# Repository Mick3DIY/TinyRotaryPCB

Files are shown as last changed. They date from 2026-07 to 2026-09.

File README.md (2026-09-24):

<picture>
    MadeForBournsPec11r(forthebadge.com)
</picture>

# TinyRotaryPCB

A tiny PCB (with surface resistors) for the BOURNS PEC11R rotary encoder.

## Printed Circuit Board (PCB) :

As part of an educational project, the schematic and PCB are made with [KiCad](https://www.kicad.org) version 9 ([kicad](kicad/) folder).

:bulb: All important parameters are stored in the schematic/PCB editors **text variables** (common project variables).

The TinyRotaryPCB itself with the rotary encoder (in reverse side for panel mount), dimensions (mm) :

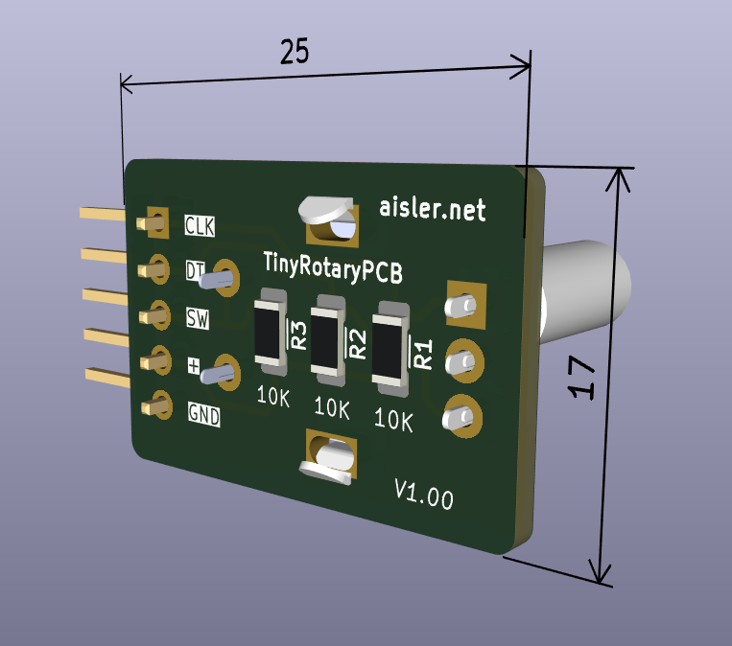
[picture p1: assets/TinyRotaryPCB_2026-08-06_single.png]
Single TinyRotaryPCB


The panelization option (2x2 boards with stencil) was generated with the KiCad plugin [KiKit](https://github.com/yaqwsx/KiKit), dimensions (mm) in [kicad/panel](kicad/panel/) folder :

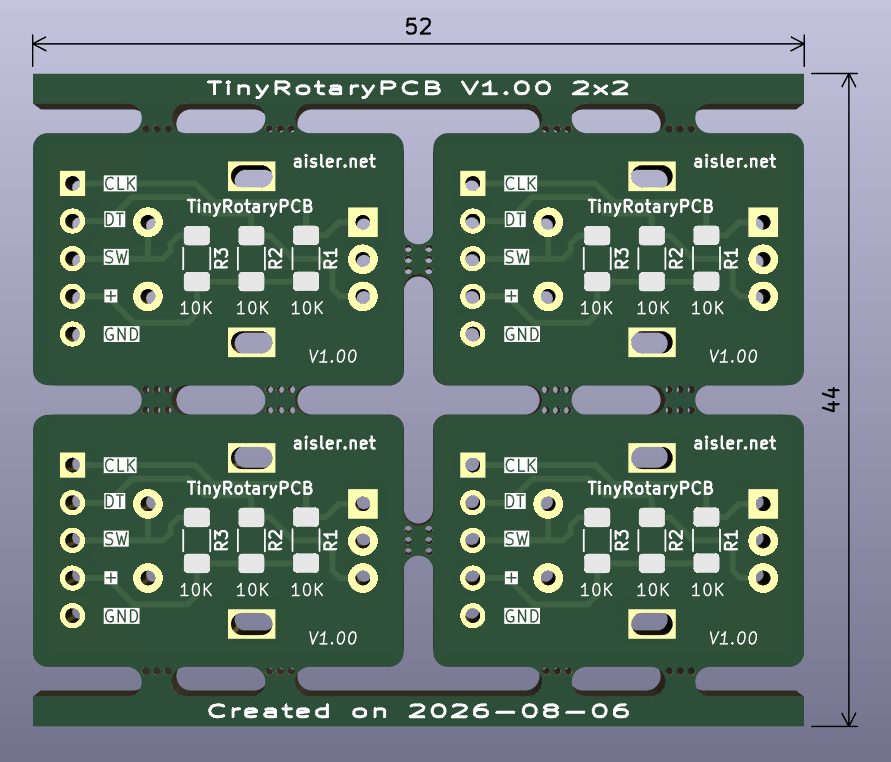
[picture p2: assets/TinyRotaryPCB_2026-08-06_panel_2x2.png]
Panelization TinyRotaryPCB


Thanks to [AISLER](https://aisler.net) PCB manufacturer :eu:

Other useful plugins for KiCad :
* AISLER Push for KiCad : https://github.com/aislerhq (with AISLER repository to always get the latest updates)
* Interactive HTML BOM : https://github.com/openscopeproject/InteractiveHtmlBom
* Board2Pdf : https://gitlab.com/dennevi/Board2Pdf
* Solarized Dark Theme : https://github.com/pointhi/kicad-color-schemes

Get a unique 10€ coupon code in <ins>your first order</ins> in [AISLER](https://aisler.net) with my referral code : `MakeInEurope-ECYPW` :heart:

The shell script to easily generate panels (in [kicad](kicad/) folder)… :laughing:

```shell
#!/bin/bash
# TinyRotaryPCB with KiCad and KiKit plugin for PCB panelization
# GitHub project : https://github.com/Mick3DIY/TinyRotaryPCB
# KiCad documentation : https://www.kicad.org
# KiKit plugin documentation : https://github.com/yaqwsx/KiKit

# Input and output files
INPUT_FILE="TinyRotaryPCB.kicad_pcb"
OUTPUT_DIR="panel"
OUTPUT_FILE="${OUTPUT_DIR}/TinyRotaryPCB_panel.kicad_pcb"

# Layout parameters, by default 2x2 -> panelize.sh <rows> <cols> parameters
LAYOUT_ROWS="${1:-2}"
LAYOUT_COLS="${2:-2}"
LAYOUT_SPACE="2mm"

# Tab parameters
TAB_TYPE="fixed"
TAB_HWIDTH="2mm"
TAB_VWIDTH="2mm"
TAB_VCOUNT="2"

# Cuts parameters
CUTS="mousebites; drill: 0.5mm; spacing: 0.75mm; offset: -0.3mm; prolong: 0.5mm"

# Framing parameters
FRAME_TYPE="railstb"
FRAME_WIDTH="2mm"
FRAME_SPACE="2mm"

# Text parameters
TEXT_HEIGHT="0.8mm"
TEXT_VOFFSET_POS="1mm"
TEXT_VOFFSET_NEG="-1mm"
TEXT_JUSTIFY="hjustify: center; vjustify: center;"
POST_MILLRADIUS="1mm"

# Ensure output directory exist
mkdir -p "${OUTPUT_DIR}"

# Kikit command with all parameters
kikit panelize \
    --layout "grid; rows: ${LAYOUT_ROWS}; cols: ${LAYOUT_COLS}; space: ${LAYOUT_SPACE}" \
    --tabs "${TAB_TYPE}; hwidth: ${TAB_HWIDTH}; vwidth: ${TAB_VWIDTH}; vcount: ${TAB_VCOUNT}" \
    --cuts "${CUTS}" \
    --framing "${FRAME_TYPE}; width: ${FRAME_WIDTH}; space: ${FRAME_SPACE};" \
    --text "simple; text: {boardTitle} {boardRevision} ${LAYOUT_COLS}x${LAYOUT_ROWS}; anchor: mt; voffset: ${TEXT_VOFFSET_POS}; height: ${TEXT_HEIGHT}; ${TEXT_JUSTIFY}" \
    --text2 "simple; text: Created on {boardDate}; anchor: mb; voffset: ${TEXT_VOFFSET_NEG}; height: ${TEXT_HEIGHT}; ${TEXT_JUSTIFY}" \
    --post "millradius: ${POST_MILLRADIUS}" \
    "${INPUT_FILE}" "${OUTPUT_FILE}"

# Check if the command succeeded
if [ $? -eq 0 ]; then
    echo "Panelization successful : ${OUTPUT_FILE}"
else
    echo "Error : Panelization failed"
    exit 1
fi
```

More panelization examples in KiKit plugin documentation : https://yaqwsx.github.io/KiKit/latest/panelization/examples/

## Logic analyser with the rotary encoder :

To understand how a rotary encoder "pulses" works, it is useful to visualise it with a software/hardware logic analysers.

Here an example with the same schematic (pins A, B, SW) in [Sigrok](https://sigrok.org) and PulseView softwares :

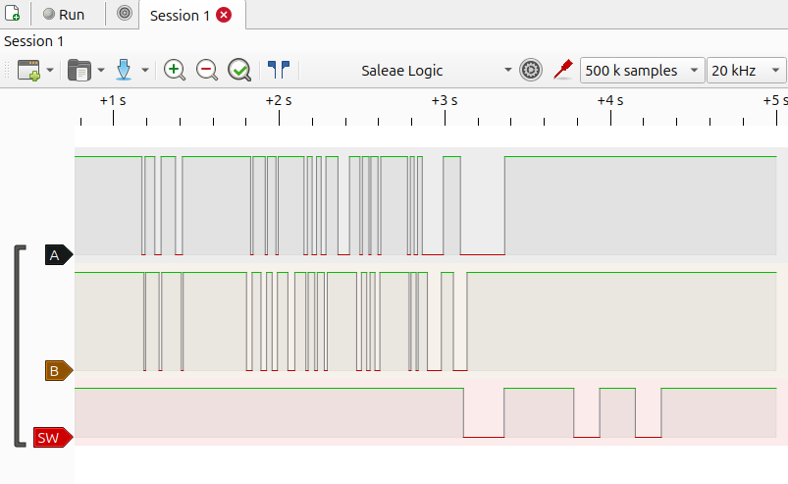
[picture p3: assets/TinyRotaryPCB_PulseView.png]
PulseViewExample


## TODO :

- [x] Add PDF files for the schematic, PCBs (single, panelization)
- [x] Add a screenshot from the logic analyser [Sigrok](https://sigrok.org)
- [x] Add link to the Elektor Ebook "Logic Analyzers in Practice" from Jörg Rippel
- [ ] Add more files and examples, any ideas ? :laughing:

## Documentation :

BOURNS PEC11R Series 12 mm incremental rotary encoder (PEC11R-4220F-S0024) :
* https://www.bourns.com/resources/rohs/encoders/contacting-encoders
* https://www.bourns.com/docs/product-datasheets/pec11r.pdf

Sigrok, PulseView softwares, all cross-platform : https://sigrok.org :clap:

Elektor Ebook "Logic Analyzers in Practice" from Jörg Rippel :
* https://www.elektor.fr/products/logic-analyzers-in-practice-e-book :ok_hand:

> [!NOTE]
> Big thanks to the open-source, [KiCad](https://www.kicad.org) and plugins communities. :heart:

Happy soldering & have fun ! :partying_face:

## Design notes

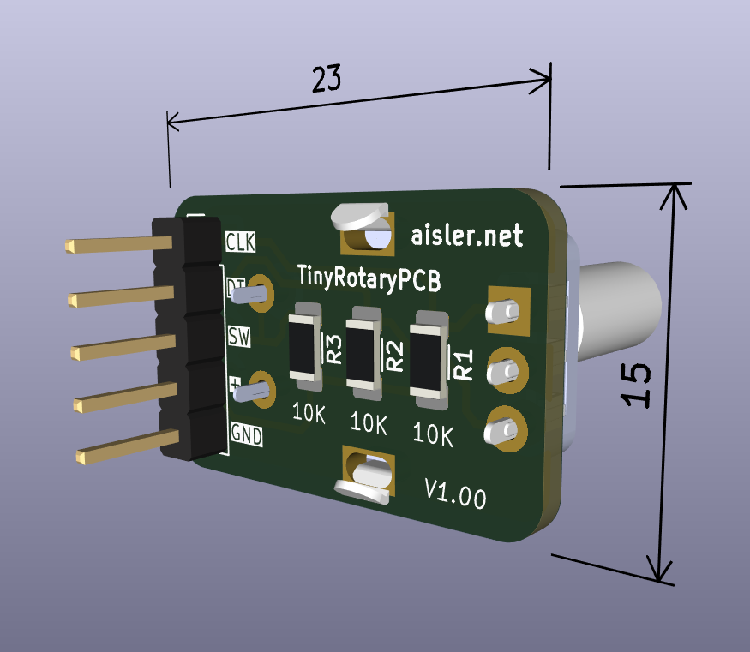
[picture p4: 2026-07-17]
assets/TinyRotaryPCB_2026-07-17_single.png

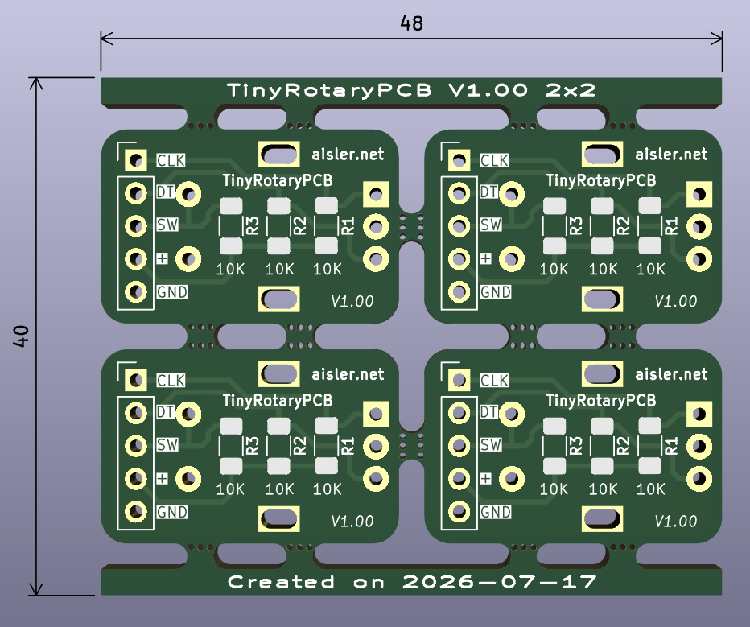
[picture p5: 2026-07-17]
assets/TinyRotaryPCB_2026-07-17_panel_2x2.png

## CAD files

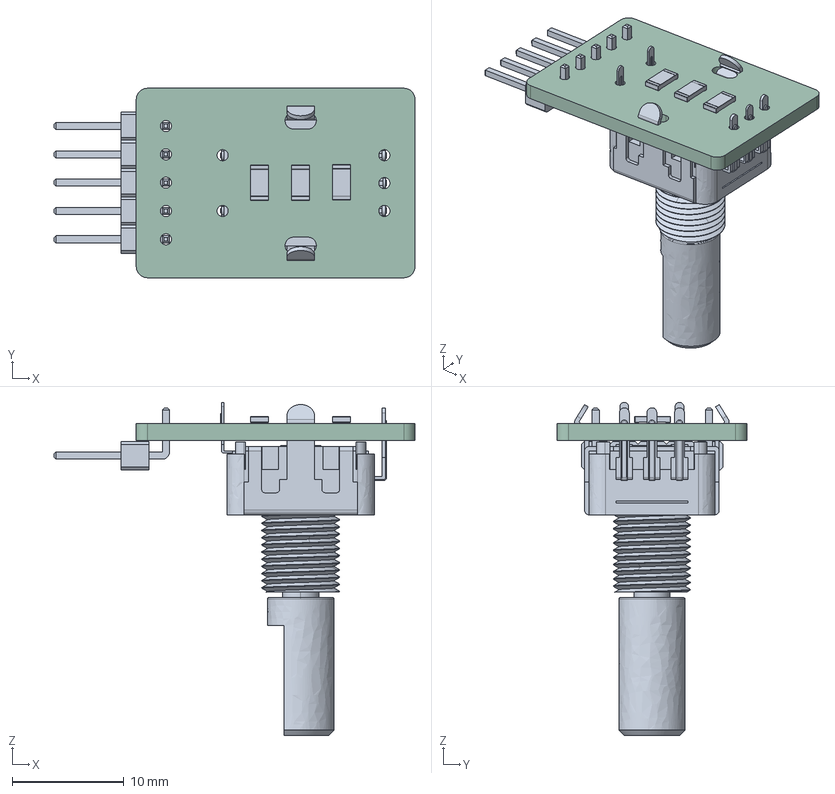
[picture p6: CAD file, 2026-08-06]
kicad/TinyRotaryPCB.step
32.4 x 17.0 x 29.9 mm
R_1206_3216Metric x 3
PinHeader_1x05_P2.54mm_Horizontal
PEC11R-4220F-S0024
TinyRotaryPCB_PCB

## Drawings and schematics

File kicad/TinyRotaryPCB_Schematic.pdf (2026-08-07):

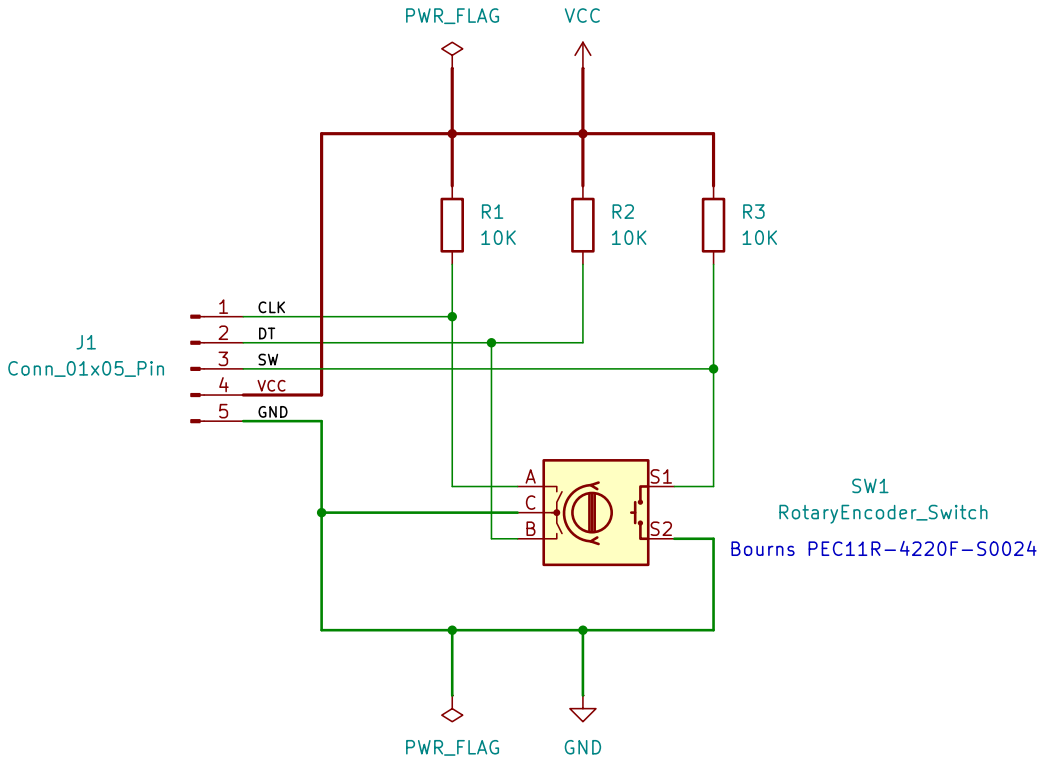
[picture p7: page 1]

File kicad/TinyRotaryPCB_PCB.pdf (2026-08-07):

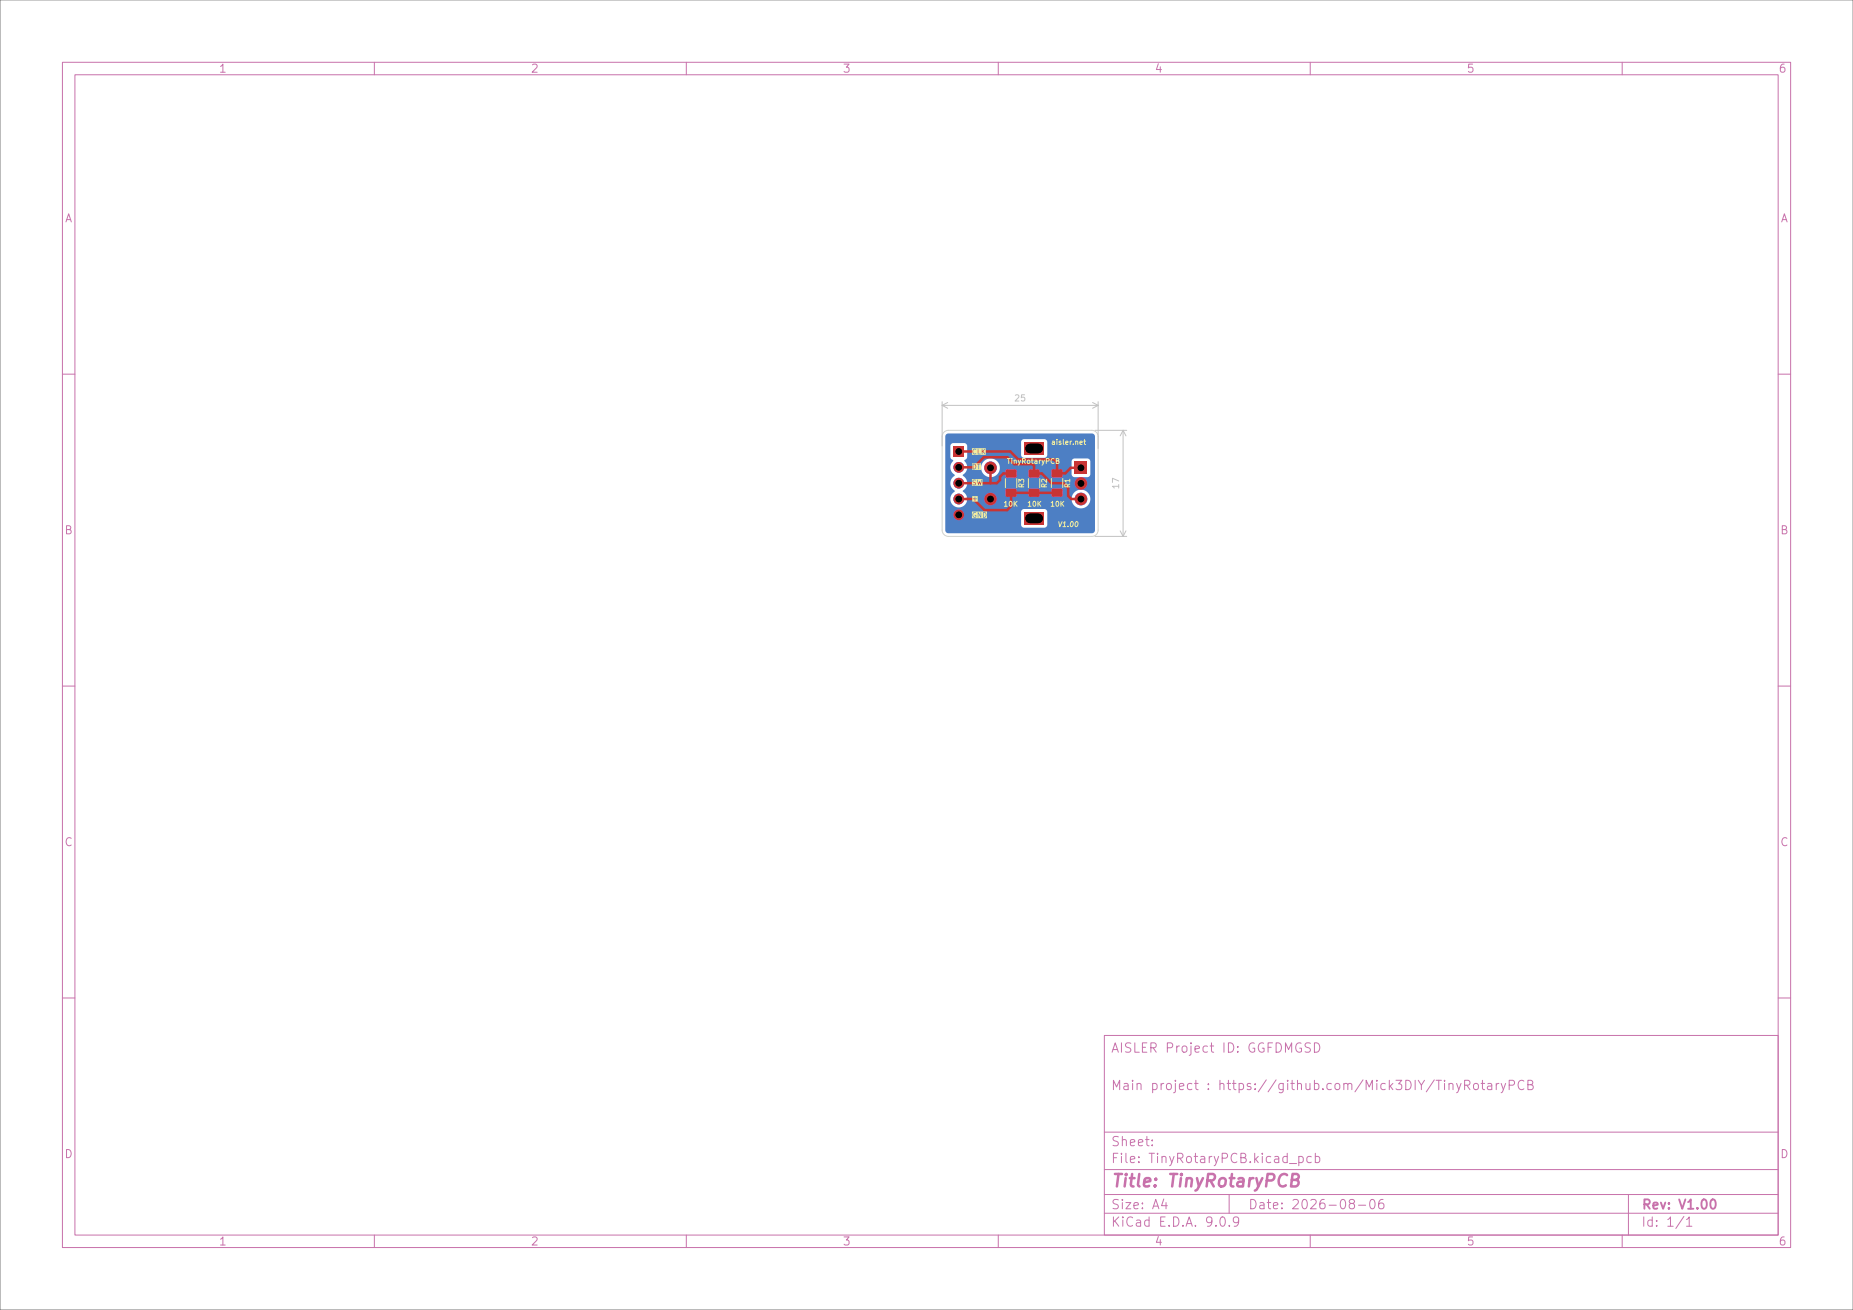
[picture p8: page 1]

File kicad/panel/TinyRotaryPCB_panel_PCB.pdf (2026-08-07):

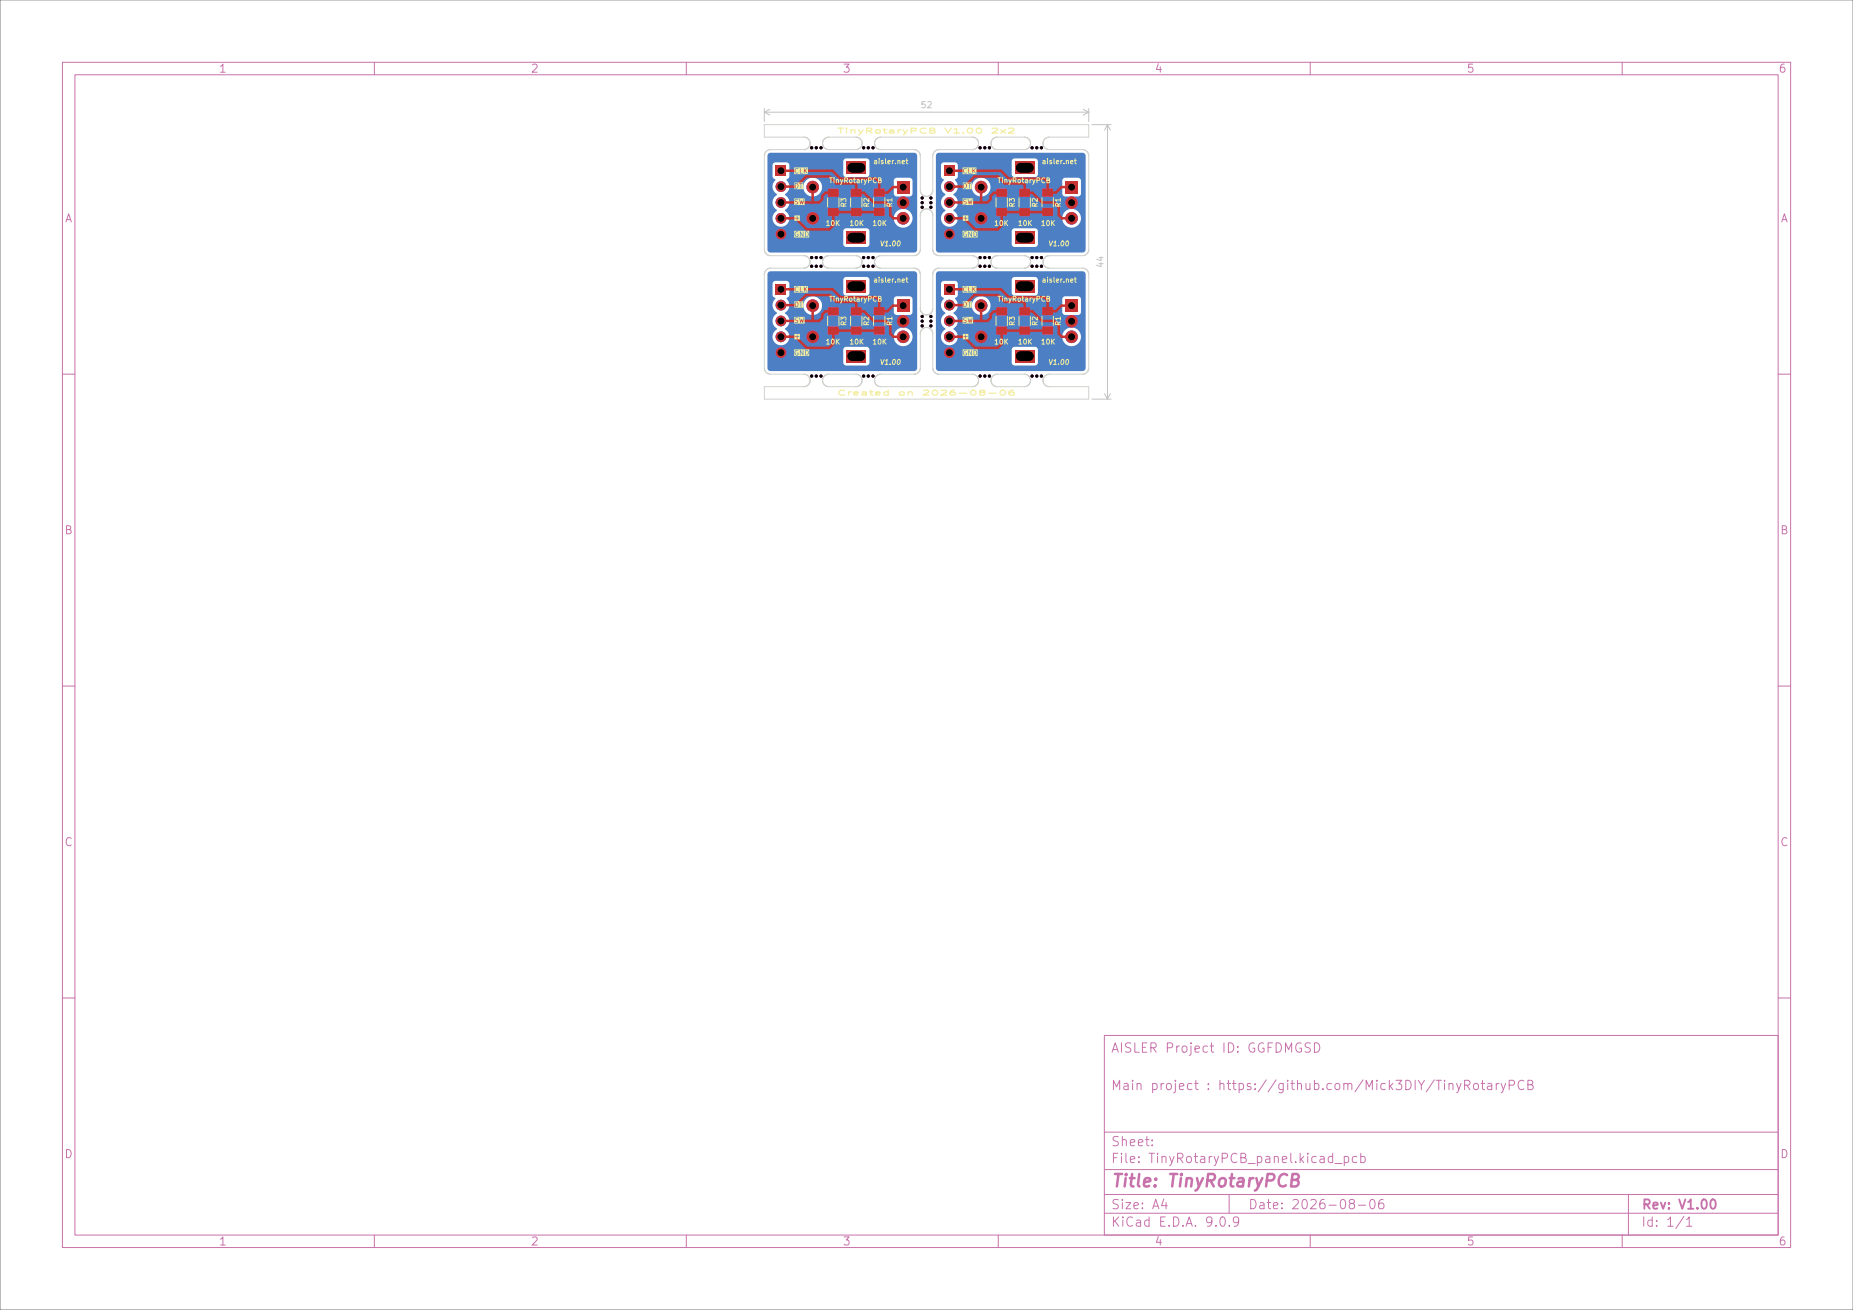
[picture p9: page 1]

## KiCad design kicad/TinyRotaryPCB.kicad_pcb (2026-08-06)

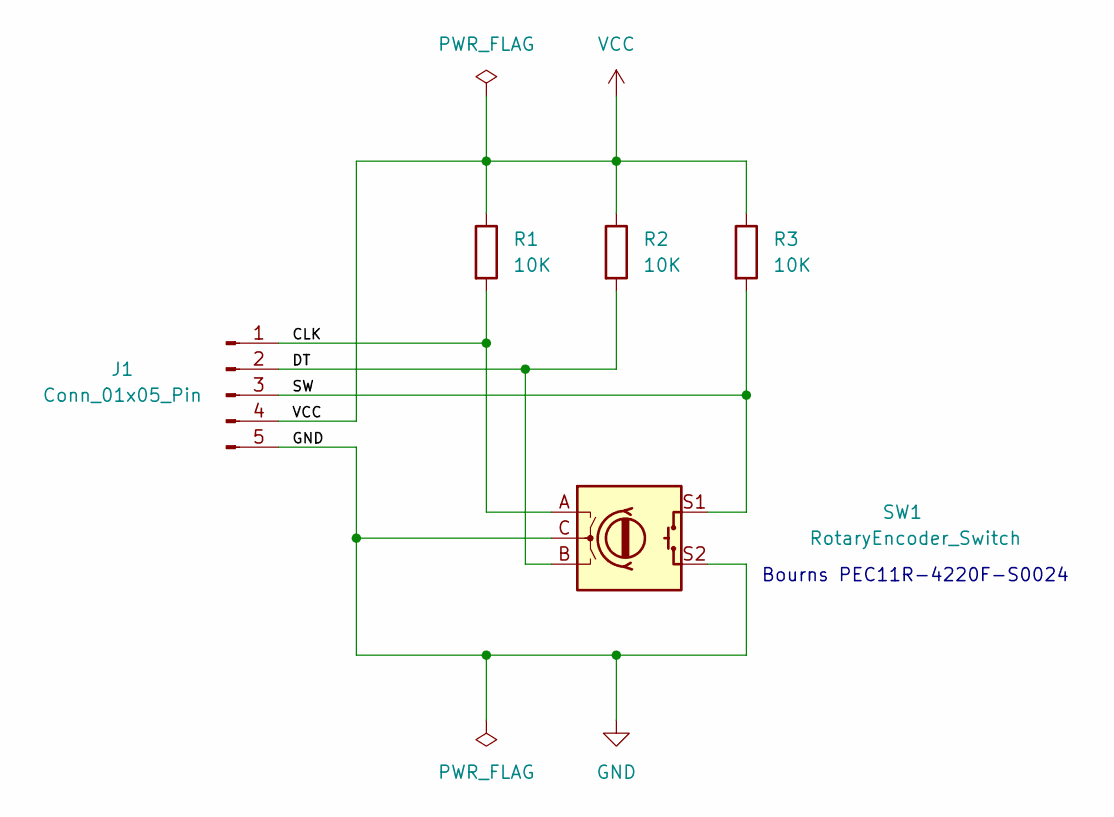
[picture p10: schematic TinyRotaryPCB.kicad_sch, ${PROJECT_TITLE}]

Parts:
J1: Conn_01x05_Pin; PinHeader_1x05_P2.54mm_Horizontal_Without_Silkscreen
R1, R2, R3: 10K; R_1206_3216Metric_Pad1.30x1.75mm_HandSolder
SW1: RotaryEncoder_Switch; RotaryEncoder_Bourns_Vertical_PEC11R-4xxxF-Sxxxx

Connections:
/CLK: J1.1, R1.2, SW1.A
/DT: J1.2, R2.2, SW1.B
/SW: J1.3, R3.2, SW1.S1
GND: J1.5, SW1.C, SW1.S2
VCC: J1.4, R1.1, R2.1, R3.1

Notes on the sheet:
Bourns PEC11R-4220F-S0024

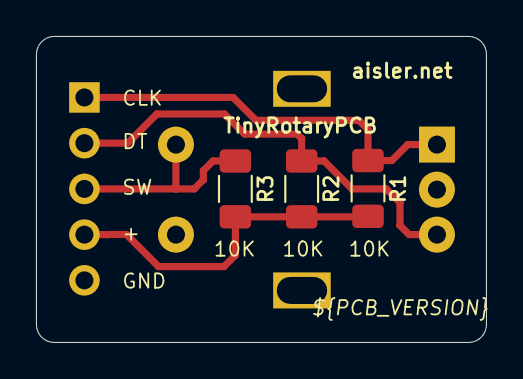
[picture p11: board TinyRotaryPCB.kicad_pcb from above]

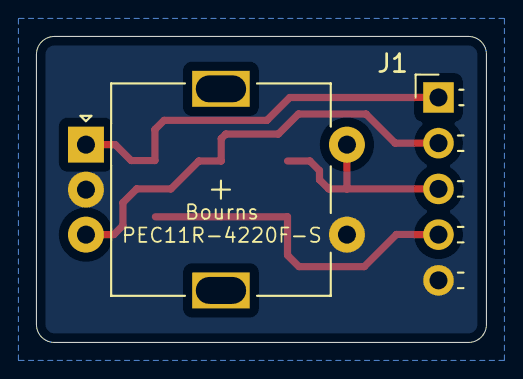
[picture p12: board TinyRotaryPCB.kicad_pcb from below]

Board: 2 copper layers, 25.0 x 17.0 mm, 5 parts (2 on the bottom side), 5 nets.

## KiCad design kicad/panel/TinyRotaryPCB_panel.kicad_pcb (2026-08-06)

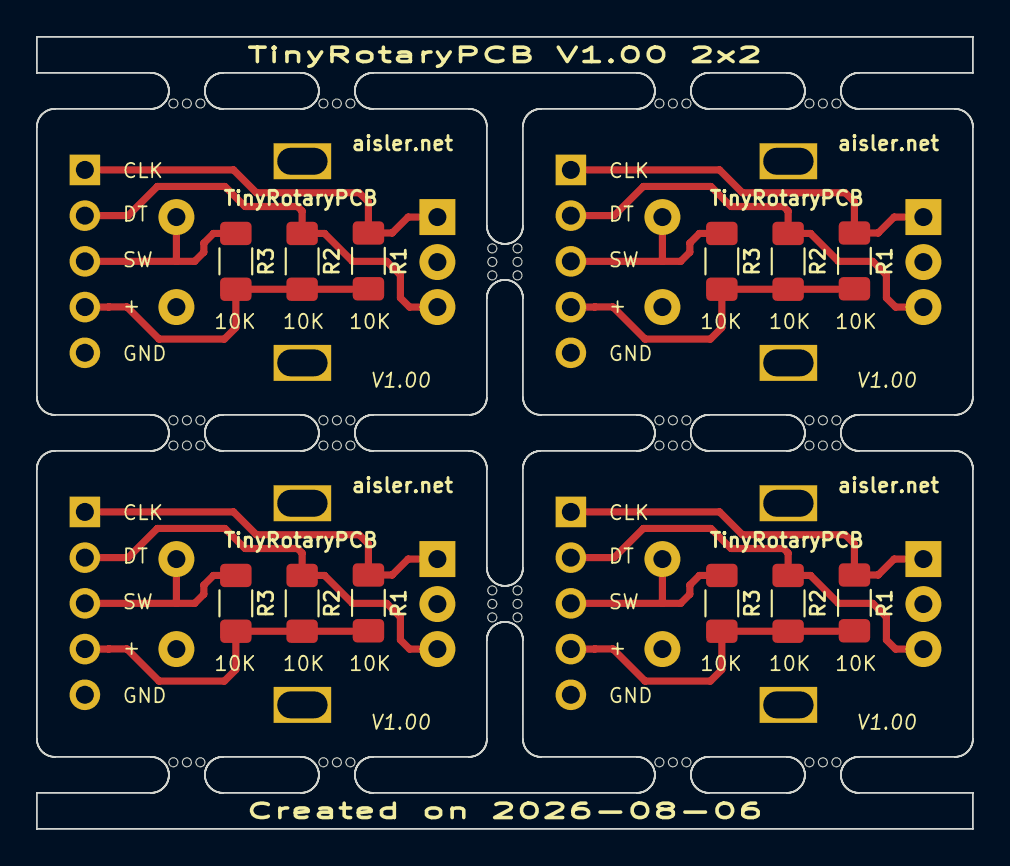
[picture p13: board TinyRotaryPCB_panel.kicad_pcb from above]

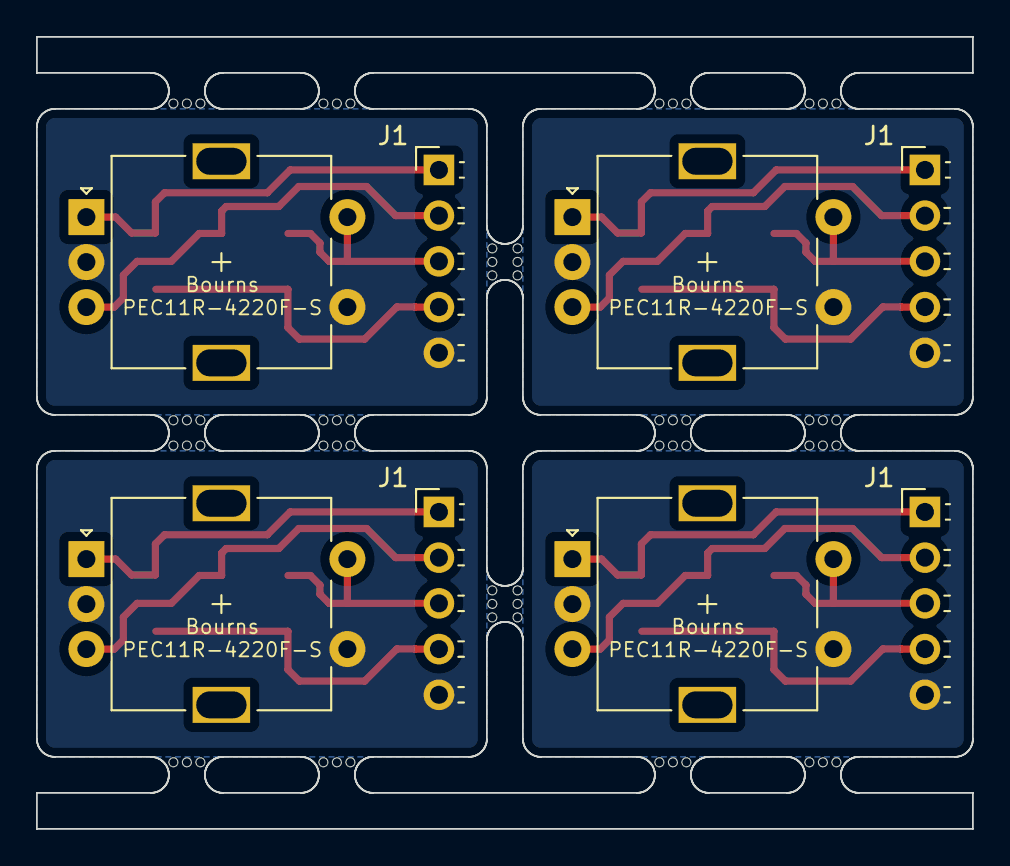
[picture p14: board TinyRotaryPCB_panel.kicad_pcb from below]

Board: 2 copper layers, 52.0 x 44.0 mm, 80 parts (8 on the bottom side), 20 nets.

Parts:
J1, J1#2, J1#3, J1#4: Conn_01x05_Pin; PinHeader_1x05_P2.54mm_Horizontal_Without_Silkscreen
KiKit_MB_1_2, KiKit_MB_1_3, KiKit_MB_1_4, KiKit_MB_2_2, KiKit_MB_2_3, KiKit_MB_2_4, KiKit_MB_3_2, KiKit_MB_3_3, KiKit_MB_3_4, KiKit_MB_4_2, KiKit_MB_4_3, KiKit_MB_4_4, KiKit_MB_5_2, KiKit_MB_5_3, KiKit_MB_5_4, KiKit_MB_6_2, KiKit_MB_6_3, KiKit_MB_6_4, KiKit_MB_7_2, KiKit_MB_7_3, KiKit_MB_7_4, KiKit_MB_8_2, KiKit_MB_8_3, KiKit_MB_8_4, KiKit_MB_9_2, KiKit_MB_9_3, KiKit_MB_9_4, KiKit_MB_10_2, KiKit_MB_10_3, KiKit_MB_10_4, KiKit_MB_11_2, KiKit_MB_11_3, KiKit_MB_11_4, KiKit_MB_12_2, KiKit_MB_12_3, KiKit_MB_12_4, KiKit_MB_13_2, KiKit_MB_13_3, KiKit_MB_13_4, KiKit_MB_14_2, KiKit_MB_14_3, KiKit_MB_14_4, KiKit_MB_15_2, KiKit_MB_15_3, KiKit_MB_15_4, KiKit_MB_16_2, KiKit_MB_16_3, KiKit_MB_16_4, KiKit_MB_17_2, KiKit_MB_17_3, KiKit_MB_17_4, KiKit_MB_18_2, KiKit_MB_18_3, KiKit_MB_18_4, KiKit_MB_19_2, KiKit_MB_19_3, KiKit_MB_19_4, KiKit_MB_20_2, KiKit_MB_20_3, KiKit_MB_20_4: NPTH
R1, R1#2, R1#3, R1#4, R2, R2#2, R2#3, R2#4, R3, R3#2, R3#3, R3#4: 10K; R_1206_3216Metric_Pad1.30x1.75mm_HandSolder
SW1, SW1#2, SW1#3, SW1#4: RotaryEncoder_Switch; RotaryEncoder_Bourns_Vertical_PEC11R-4xxxF-Sxxxx

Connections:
Board_0-/CLK: J1#4.1, R1.2, SW1#2.A
Board_0-/DT: J1#4.2, R2.2, SW1#2.B
Board_0-/SW: J1#4.3, R3#2.2, SW1#2.S1
Board_0-GND: J1#4.5, SW1#2.C, SW1#2.S2
Board_0-VCC: J1#4.4, R1.1, R2.1, R3#2.1
Board_1-/CLK: J1#2.1, R1#3.2, SW1#3.A
Board_1-/DT: J1#2.2, R2#4.2, SW1#3.B
Board_1-/SW: J1#2.3, R3#3.2, SW1#3.S1
Board_1-GND: J1#2.5, SW1#3.C, SW1#3.S2
Board_1-VCC: J1#2.4, R1#3.1, R2#4.1, R3#3.1
Board_2-/CLK: J1#3.1, R1#2.2, SW1#4.A
Board_2-/DT: J1#3.2, R2#3.2, SW1#4.B
Board_2-/SW: J1#3.3, R3#4.2, SW1#4.S1
Board_2-GND: J1#3.5, SW1#4.C, SW1#4.S2
Board_2-VCC: J1#3.4, R1#2.1, R2#3.1, R3#4.1
Board_3-/CLK: J1.1, R1#4.2, SW1.A
Board_3-/DT: J1.2, R2#2.2, SW1.B
Board_3-/SW: J1.3, R3.2, SW1.S1
Board_3-GND: J1.5, SW1.C, SW1.S2
Board_3-VCC: J1.4, R1#4.1, R2#2.1, R3.1

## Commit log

2026-07-17 Add KiCad project, assets
    [TinyRotaryPCB.kicad_pcb, TinyRotaryPCB.kicad_sch, TinyRotaryPCB_panel.kicad_pcb]
2026-07-18 Update README.md, KiCad text variables
    [TinyRotaryPCB.kicad_pcb, TinyRotaryPCB.kicad_sch, TinyRotaryPCB_panel.kicad_pcb]
2026-07-19 Update README.md, KiCad project with step file
    [TinyRotaryPCB.kicad_pcb, TinyRotaryPCB.step]
2026-08-06 Update KiCad project, horizontal pin header
    [TinyRotaryPCB.kicad_pcb, TinyRotaryPCB.kicad_sch, TinyRotaryPCB.step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]
2026-08-07 Add PDF files for the schematic, PCBs (single, panelization)
2026-10-05 Update footprint warning
    [TinyRotaryPCB.kicad_pcb, TinyRotaryPCB.step]
